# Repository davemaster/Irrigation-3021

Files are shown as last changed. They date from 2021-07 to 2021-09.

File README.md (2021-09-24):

# Irrigation-3021
imagen(https://blogs.embarcadero.com/building-good-with-cbuilder-contest-results/)

https://blogs.embarcadero.com/building-good-with-cbuilder-contest-results/ 
https://youtube.com/embed/tNYx-wSfjVc

imagen

How Bluetooth Technology can improve the use of water resources worldwide. Programming using [C++ Builder 10.3 Community Edition](https://www.embarcadero.com/es/products/cbuilder/starter) was surprisly very faster than the turtle of Android Studio and its eternal indexing-nightmares; So, its time to move forward using this IDE, in this project, using the multi-device features. 

The goal, more control over the water use in irrigation issues, first in my mom's garden, then in the city parks, then Farmlands, then in any water distribution activity worldwide. Thanks to the [Building Good with C++Builder Contest](https://blogs.embarcadero.com/building-good-with-cbuilder-contest/) for giving this oportunity.

# Project Resume
The system is going to use a bluetooth capable device to control a valve to irrigate a plant. The control-device can be a laptop/pc or a smartphone (Android or iOS). These devices control through bluetooth wireless link an Arduino UNO board connected to a HC-05 bluetooth module; so this last can open/close the solenoid valve by a relay; according the following modes: 1. Based on sensors (humidity, water tank level, and rain intensitivity) the Arduino will decide when to open/close the valve to properly water the plant. The sensors values will be compared with setpoints to make decisions. Mode 2. Test mode, we can open/close valve no matter the sensors values. Mode 3, using irrigation schedules, ie, time defined periods when the valve will be open.

# Needed Parts
1. Mobile Phone: Iphone, Android or laptop/pc Bluetooth capable. C++ Builder 10.3 can program them all with ONE project at the same time; pretty GOOD!!!.

imagen

2. Arduino Board: UNO, NANO, MEGA, etc. https://www.arduino.cc/en/Main/Products

imagen

3. HC-05 Bluetooth Module https://www.siarperu.com/store/#view=00011&busq=hc-05

imagen

4. A 12V solenoid Valve https://www.sparkfun.com/products/10456

imagen
 
5. Some Protoboards cabling, female-male, male-male or female-female https://naylampmechatronics.com/accesorios-y-prototipado/26-cable-para-protoboard.html

imagen

6. Sensors for Humidity moisture, rain intensitivity, and water level:

imagen  imagen imagen

# Needed Software
1. Embarcadero C++ Builder 10.3 Community Edition https://www.embarcadero.com/products/cbuilder/starter or lastest https://embarcadero.com/products/cbuilder

imagen

2. Arduino IDE 1.8.15 https://www.arduino.cc/en/software

imagen

3. Any Serial Terminal (for PC Windows or Mac where the C++ Builder is installed)

imagen

4. Proteus 8.6 with Arduino libraries for simulate Arduino valve control and the sensors attached (humidity, water leve, and rain) lectures and response of the valve
   control system (circuit and firmware) to commands from Irrigation 3021 app programmed in C++ Builder. 
   
   imagen

   imagen

5. In my particular case, I used the scrcpy for see my project (Irrigation 3021) in its Android versión. https://github.com/Genymobile/scrcpy

imagen

imagen

SOURCE CODE UPDATED

In file BTReadThread.cpp, the following changes has been made:

.................................

  else if(cmd==2)
		{
			dataFromArduino=Socket->ReceiveData();

			if(dataFromArduino.Length>0)
			{
				StrReceived = TEncoding::ASCII->GetString(dataFromArduino);

				/*************************************/
				AllReceivedData+=StrReceived;

				msg=AllReceivedData;
				Synchronize(TabbedForm->WriteMemo);

				if(AllReceivedData.Length()>12)
				{
					sensors=AllReceivedData;
					Synchronize(TabbedForm->UpdateValueSensors);

					AllReceivedData="";
					Sleep(100);
				}

				#ifndef __ANDROID__
				else
					AllReceivedData="";
				#endif

				/*****************************************/

				/*msg=StrReceived;
				Synchronize(TabbedForm->WriteMemo);

				if(msg.Length()>3)
				{

					sensors=StrReceived;
					Synchronize(TabbedForm->UpdateValueSensors);

				} */
			}

			Sleep(100);
		}

..................................

imagen

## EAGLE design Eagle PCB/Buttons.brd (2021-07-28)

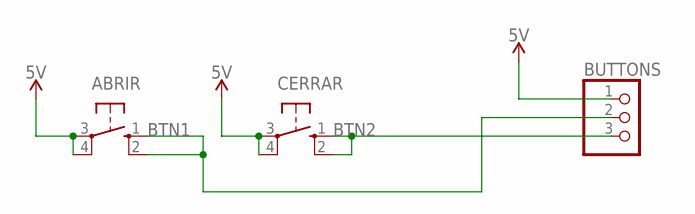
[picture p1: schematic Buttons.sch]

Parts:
ABRIR: 10-XX; B3F-10XX
BUTTONS: PINHD-1X3; 1X03
CERRAR: 10-XX; B3F-10XX

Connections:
5V: ABRIR.3, ABRIR.4 (P1), BUTTONS.1, CERRAR.3, CERRAR.4 (P1)
BTN1: ABRIR.1 (S), ABRIR.2 (S1), BUTTONS.2
BTN2: BUTTONS.3, CERRAR.1 (S), CERRAR.2 (S1)

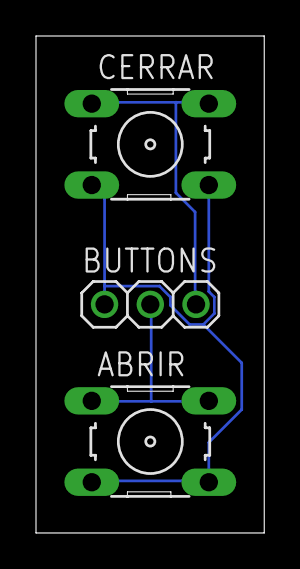
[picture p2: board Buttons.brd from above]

Board: 2 copper layers, 12.7 x 27.6 mm, 3 parts (0 on the bottom side), 3 nets.

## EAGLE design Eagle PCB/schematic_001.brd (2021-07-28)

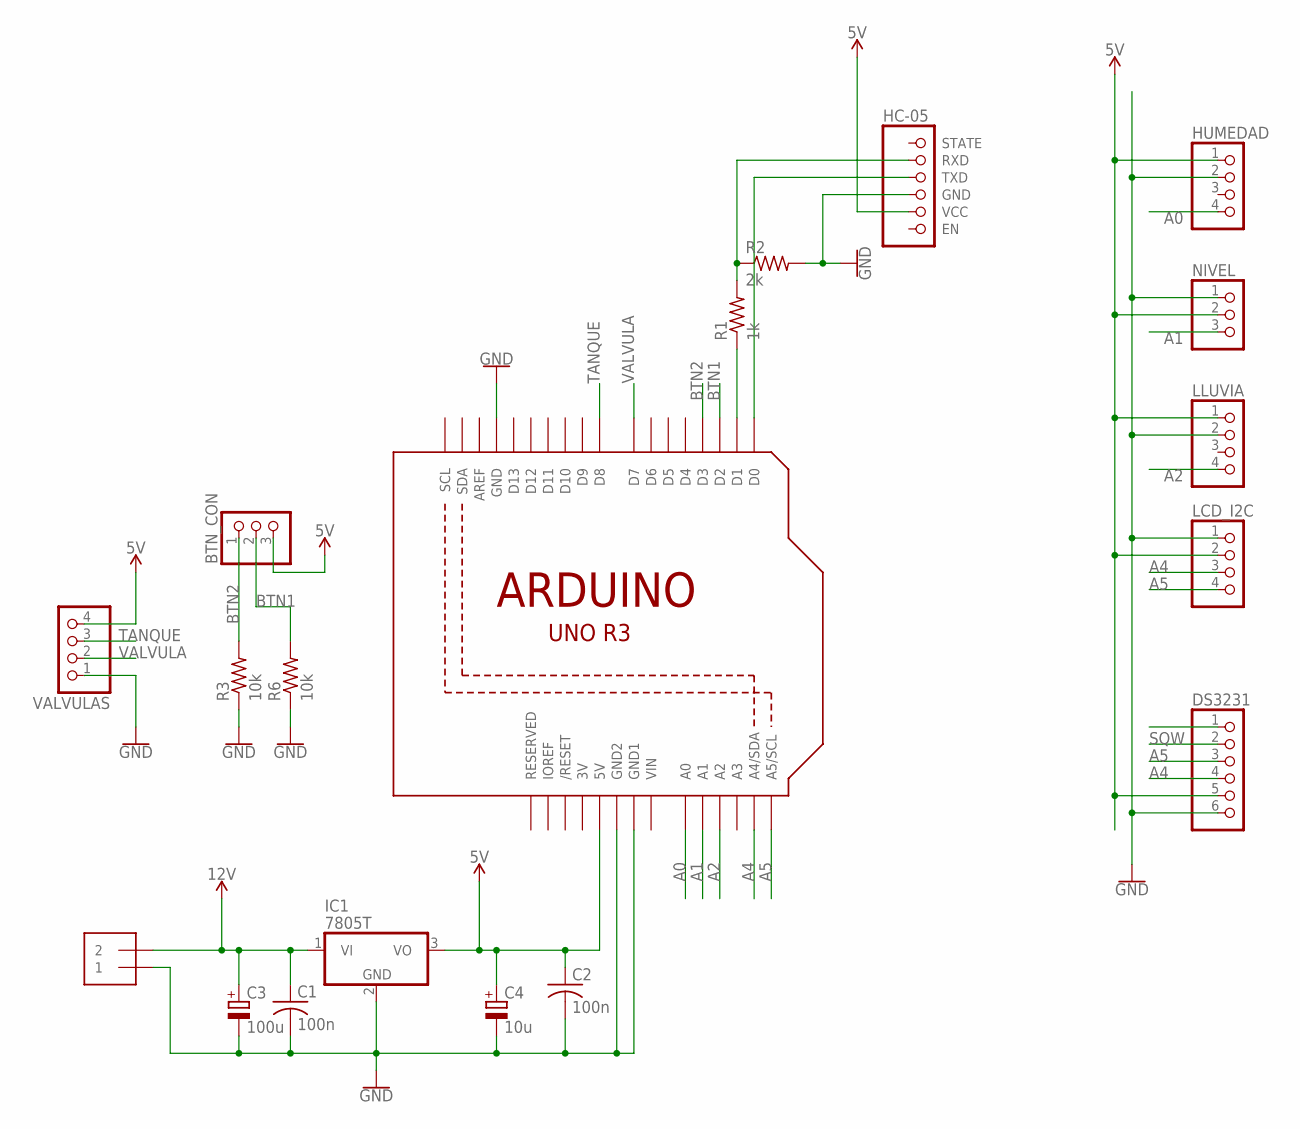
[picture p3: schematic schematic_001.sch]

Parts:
BTN_CON: PINHD-1X3; 1X03
C1, C2: 100n; C050-024X044
C3: 100u; E2,5-7
C4: 10u; E2,5-7
DS3231: PINHD-1X6; 1X06
HC-05: HC-05; 1X06
HUMEDAD: PINHD-1X4; 1X04
IC1: 7805T; TO220H
J1: 1X2-3.5MM
LCD_I2C: PINHD-1X4; 1X04
LLUVIA: PINHD-1X4; 1X04
NIVEL: PINHD-1X3; 1X03
R1: 1k; 0204/7
R2: 2k; 0204/7
R3, R6: 10k; 0204/7
U1: ARDUINOR3-BPLACE
VALVULAS: PINHD-1X4; 1X04

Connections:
3V: U1.3V
5V: BTN_CON.3, C2.1, C4.+, DS3231.5, HC-05.5 (VCC), HUMEDAD.1, IC1.3 (VO), LCD_I2C.2, LLUVIA.1, NIVEL.2, U1.5V, VALVULAS.4
12V: C1.1, C3.+, IC1.1 (VI), J1.2
A0: HUMEDAD.4, U1.A0
A1: NIVEL.3, U1.A1
A2: LLUVIA.4, U1.A2
A4: DS3231.4, LCD_I2C.3, U1.A4 (A4/SDA)
A5: DS3231.3, LCD_I2C.4, U1.A5 (A5/SCL)
BTN1: BTN_CON.2, R6.2, U1.D2
BTN2: BTN_CON.1, R3.2, U1.D3
GND: C1.2, C2.2, C3.-, C4.-, DS3231.6, HC-05.4 (GND), HUMEDAD.2, IC1.2 (GND), J1.1, LCD_I2C.1, LLUVIA.2, NIVEL.1, R2.2, R3.1, R6.1, U1.GND, U1.GND1, U1.GND2, VALVULAS.1
unnamed: HC-05.2 (RXD), R1.2, R2.1
unnamed: R1.1, U1.D1
unnamed: HC-05.3 (TXD), U1.D0
SQW: DS3231.2
TANQUE: U1.D8, VALVULAS.3
VALVULA: U1.D7, VALVULAS.2
VIN: U1.VIN

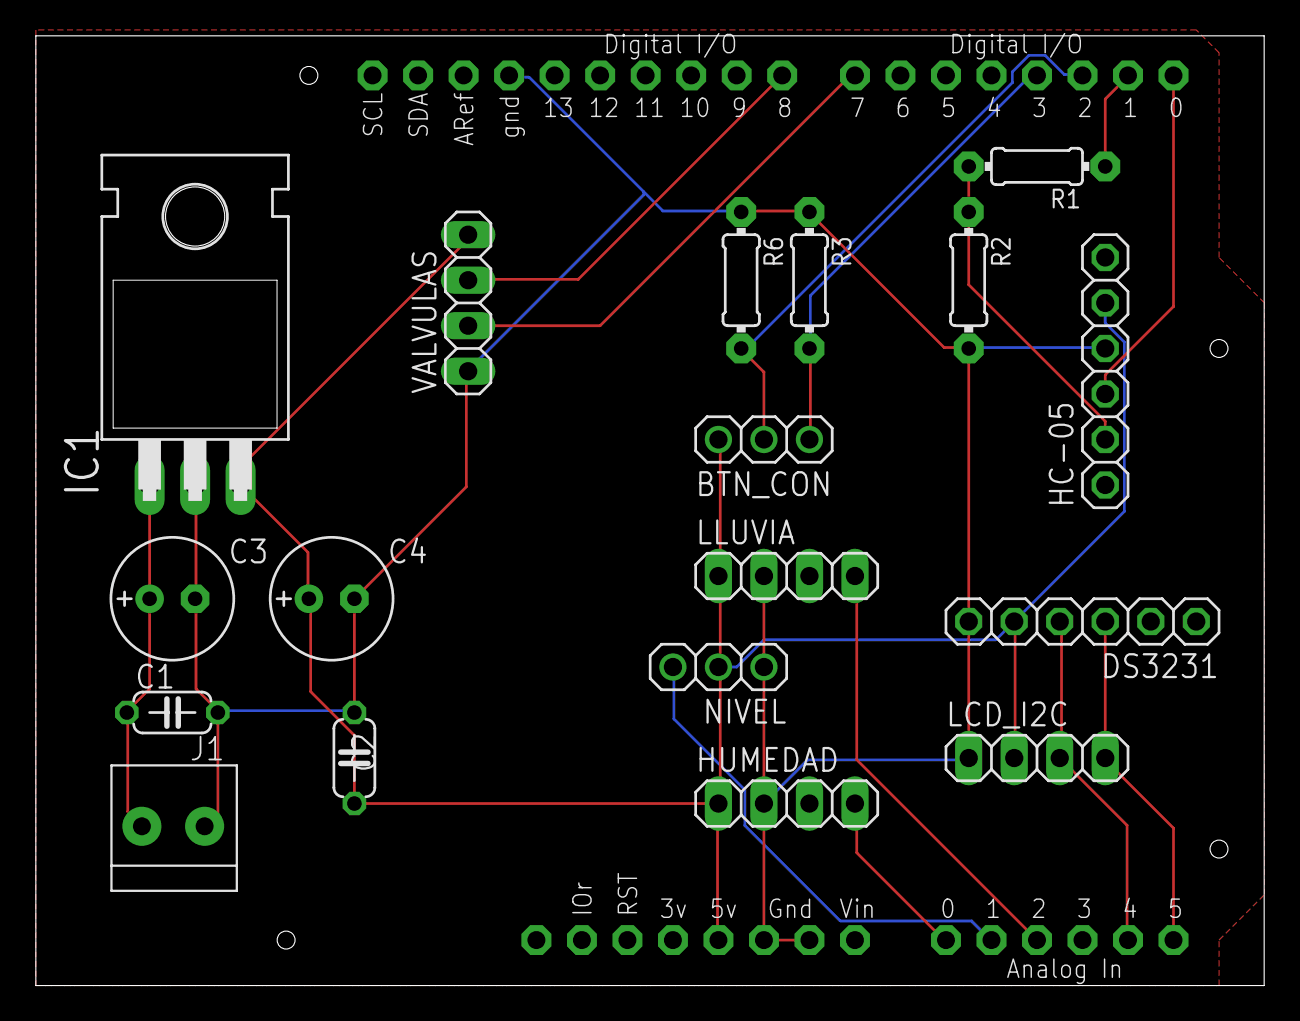
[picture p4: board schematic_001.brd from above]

Board: 2 copper layers, 68.6 x 53.0 mm, 19 parts (0 on the bottom side), 15 nets.

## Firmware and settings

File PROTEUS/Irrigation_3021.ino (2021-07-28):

/****************************************************************************************************************************
 * Project     :    Irrigation 3021
 * Programmer  :    David Elías Flores Escalante
 * github      :
 * Description :    Arduino sketch for Irrigation 3021 system for save water in irrigation applications in home, agriculture, 
 *                  etc. This for Contest C++ Builder Code for Good 2021
 **************************************************************************************************************************** 
 */


#include <Wire.h>
#include <LiquidCrystal_I2C.h>
#include <DS3231.h>


//********************************* Define an LCD object using I2C interface  ***********************************************

//LiquidCrystal_I2C lcd(0x27, 16, 2); // set the LCD address to 0x27 for a 16 chars and 2 line display
LiquidCrystal_I2C lcd(0x20,16,2);  // set the LCD address to 0x27 for a 16 chars and 2 line display

//**********************************************Variables RTC DS3231 ********************************************************
DS3231 clock;

byte Year;
byte Month;
byte Date;
//byte DoW;
byte Hour;
byte Minute;
byte Second;
int lastSecond = 20; //Initial absurd second value

bool h12Flag;
bool pmFlag;

//***************************************************************************************************************************

//******************************************Variables RTC DS3231 ************************************************************
int sensorHumedad = A0;                 //   Humidity Sensor
int sensorNivelAgua = A1;               //   Water Level Sensor
int sensorLluvia = A2;                  //   Rain Intensitivity Sensor
int valvePin = 7;                       //   Valve for water
int valveTanquePin = 8;                 //   valve of tank of water from rain
//int ledPin = 13;

// countdown timer vars
int openMinutes = 5;                    //   time in minutes during valve will be open
int openSeconds = 0;
RTClib myRTC;
DateTime dTime;
long startTime, currentTime;
//long endTime;



// setpoints
const int defaultHumedad = 400;         //   default humidity sensor setPoint
const int defaultNivel   = 500;         //   default water level sensor setPoint
const int defaultLluvia  = 500;         //   default rain intenwitivity sensor setPoint

int setPointHumedad      = 400;         //   current humidity sensor setPoint
int setPointNivelAgua    = 500;         //   current water level sensor setPoint
int setPointLluvia       = 500;         //   current rain intenwitivity sensor setPoint

const int BTN_OPEN       = 3;           //   button arduino pin for open valve
const int BTN_CLOSE      = 2;           //   button arduino pin for close valve

int buttonState          = 0;           //   variable for reading the pushbutton status
int valveStatus          = 0;           //   variable valve status 1: open     0: closed
int valveTanqueStatus    = 0;           //   variable valve status 1: open     0: closed

long sensorValueHumedad;                //   value of Analog port for humidity
long sensorValueNivelAgua;              //   value of Analog Port for Water Level
long sensorValueLluvia;                 //   value of Analog port for Rain Intensitivity

//int limit = 300;

#define SAMPLES 10                      //   number of samples for Analog ports lectures

/***************************************
  SERIAL BLUETOOTH LINK
**************************************/

//int cmd = 0;
int Modo = 3;
byte prevVal1, prevVal2, val, dataBuffer[256];
boolean dataIn = false;
int dataPos = 0;

/*******************************************************************************************

   Function setup, executed ONCE for set Arduino features

********************************************************************************************/
void setup()
{
  /***********************************************************************
     buttons open & close valve into interrupted fired ports (2 & 3 for Arduino UNO)
  ***********************************************************************/
  // digital pin 2 - open valve button
  attachInterrupt(digitalPinToInterrupt(BTN_OPEN), btnValveOpen, CHANGE);

  // digital pin 3 - close valve button
  attachInterrupt(digitalPinToInterrupt(BTN_CLOSE), btnValveClose, CHANGE);

  loadConfiguration();
}

/*******************************************************************************************

   Function for Arduino settings

********************************************************************************************/
void loadConfiguration()
{
  //pinMode(ledPin, OUTPUT);
  pinMode(valvePin, OUTPUT);              // set valvePin to OUTPUT
  pinMode(valveTanquePin, OUTPUT);        // set valveTanquePin to OUTPUT

  lcd.init();                             // initialize the LCD-I2C

  lcd.backlight();                        // turn LCD-I2C backlight on
  lcd.setCursor(0, 0);
  lcd.print("DaveWare Design.");
  lcd.setCursor(0, 1);
  lcd.print("Irrigation 3021 ");
  delay(3000);
  lcd.clear();

  //lcd.noBacklight();                    // turn LCD-I2C backlight off

  Serial.begin(9600);                     // set Serial port (Bluetooth attached here) to 9600 bps spped

  // Finally the hour, minute, and second
  Serial.println(" ");
  Serial.print(clock.getHour(h12Flag, pmFlag), DEC);
  Serial.print(" ");
  Serial.print(clock.getMinute(), DEC);
  Serial.print(" ");
  Serial.print(clock.getSecond(), DEC);
  
}

/*******************************************************************************************

   Function that read dataBuffer and get humidity setpoint sent by pc/android application

********************************************************************************************/
void getHumidityFromBT(int& humditySP)
{
  byte Temp1, Temp2;                      // temp variables for convert bytes with time values
  byte Temp3, Temp4;                      // temp variables for convert bytes with time values

  // Reading from Most to less significant digits
  Temp1 = dataBuffer[0] - 48;
  Temp2 = dataBuffer[1] - 48;
  Temp3 = dataBuffer[2] - 48;
  Temp4 = dataBuffer[3] - 48;
  humditySP = Temp1 * 1000 + Temp2 * 100 + Temp3 * 10 + Temp4;

}

/*******************************************************************************************

   Function that read dataBuffer and get Water Level setpoint sent by pc/android application

********************************************************************************************/
void getLevelFromBT(int& LevelSP)
{
  byte Temp1, Temp2;                      // temp variables for convert bytes with time values
  byte Temp3, Temp4;                      // temp variables for convert bytes with time values

  // Reading from Most to less significant digits
  Temp1 = dataBuffer[0] - 48;
  Temp2 = dataBuffer[1] - 48;
  Temp3 = dataBuffer[2] - 48;
  Temp4 = dataBuffer[3] - 48;
  LevelSP = Temp1 * 1000 + Temp2 * 100 + Temp3 * 10 + Temp4;
}


/*******************************************************************************************

   Function that read dataBuffer and get Rain Intenisivity setpoint sent by pc/android application

********************************************************************************************/
void getRainFromBT(int& RainSP)
{
  byte Temp1, Temp2;                      // temp variables for convert bytes with time values
  byte Temp3, Temp4;                      // temp variables for convert bytes with time values

  // Reading from Most to less significant digits
  Temp1 = dataBuffer[0] - 48;
  Temp2 = dataBuffer[1] - 48;
  Temp3 = dataBuffer[2] - 48;
  Temp4 = dataBuffer[3] - 48;
  RainSP = Temp1 * 1000 + Temp2 * 100 + Temp3 * 10 + Temp4;
}

/***********************************************************************************************

   Function that read dataBuffer and get Time of Valve Operation sent by pc/android application

***********************************************************************************************/
void getMinutesFromBT(int& vMinutes)
{
  byte Temp1, Temp2;                      // temp variables for convert bytes with time values
  byte Temp3, Temp4;                      // temp variables for convert bytes with time values

  // Reading from Most to less significant digits
  Temp1 = dataBuffer[0] - 48;
  Temp2 = dataBuffer[1] - 48;
  Temp3 = dataBuffer[2] - 48;
  Temp4 = dataBuffer[3] - 48;
  vMinutes = Temp1 * 1000 + Temp2 * 100 + Temp3 * 10 + Temp4;
}

/*******************************************************************************************

   Function that read dataBuffer when a "Sincronize time" is sent by pc/android application

********************************************************************************************/
void getDateFromBT(byte& Year, byte& Month, byte& Day,
                   byte& Hour, byte& Minute, byte& Second)
{
  // Call this if you notice something coming in on
  // the serial port. The stuff coming in should be in
  // the order YYMMDDHHMMSS, with an 'x' at the end.

  byte Temp1, Temp2;                      // temp variables for convert bytes with time values

  // Read Year first
  Temp1 = dataBuffer[0] - 48;
  Temp2 = dataBuffer[1] - 48;
  Year = Temp1 * 10 + Temp2;
  // now month
  Temp1 = dataBuffer[2] - 48;
  Temp2 = dataBuffer[3] - 48;
  Month = Temp1 * 10 + Temp2;
  // now date
  Temp1 = dataBuffer[4] - 48;
  Temp2 = dataBuffer[5] - 48;
  Day = Temp1 * 10 + Temp2;
  // now Day of Week
  //DoW = (byte)dataBuffer[6] - 48;
  // now Hour
  Temp1 = dataBuffer[6] - 48;
  Temp2 = dataBuffer[7] - 48;
  Hour = Temp1 * 10 + Temp2;
  // now Minute
  Temp1 = dataBuffer[8] - 48;
  Temp2 = dataBuffer[9] - 48;
  Minute = Temp1 * 10 + Temp2;
  // now Second
  Temp1 = dataBuffer[10] - 48;
  Temp2 = dataBuffer[11] - 48;
  Second = Temp1 * 10 + Temp2;
}

/*******************************************************************************************

   Function loop, this is executed continously

********************************************************************************************/
void loop()
{
  /***************************************************
     Humidity Sensor Readings
  ***************************************************/
  //set value of humidity sensor to zero
  sensorValueHumedad = 0;
  //reading samples to average measurements
  for (int ind = 0; ind < SAMPLES; ind++)
  {
    int value = analogRead(sensorHumedad);
    sensorValueHumedad = sensorValueHumedad + value;
    delay(10);                                   // wait 10 milliseconds
  }

  //humidity sensor average value
  sensorValueHumedad = sensorValueHumedad / SAMPLES;

  /***************************************************
     Water Level Sensor Readings
  ***************************************************/
  //set value of Water Level sensor to zero
  sensorValueNivelAgua = 0;

  //reading samples to average measurements
  for (int ind = 0; ind < SAMPLES; ind++)
  {
    int value = analogRead(sensorNivelAgua);     // Read the analog value form sensor
    sensorValueNivelAgua = sensorValueNivelAgua + value;
    delay(10);                                   // wait 10 milliseconds
  }
  //Water Level sensor average value
  sensorValueNivelAgua /= SAMPLES;

  /***************************************************
     Rain Intensitivity Sensor Readings
  ***************************************************/
  //set value of Rain Intensitivity sensor to zero
  sensorValueLluvia = 0;

  //reading samples to average measurements
  for (int ind = 0; ind < SAMPLES; ind++)
  {
    int value = analogRead(sensorLluvia);        // Read the analog value form sensor
    sensorValueLluvia = sensorValueLluvia + value;
    delay(10);                                   // wait 10 milliseconds
  }
  //Rain Intensitivity sensor average value
  sensorValueLluvia /= SAMPLES;

  if (Modo == 3) //Normal Mode / Modo Normal
  {
    char buffer[20];
    int curSecond = clock.getSecond();

    if (lastSecond != curSecond)
    {
      sprintf(buffer, "Hora--> %02d:%02d:%02d", clock.getHour(h12Flag, pmFlag)
              , clock.getMinute()
              , lastSecond); //,clock.getSecond());
      lastSecond = curSecond;

      //Serial.println(buffer);
      lcd.setCursor(0, 1);
      lcd.print(buffer);
    }

    if (sensorValueLluvia > setPointLluvia)
    {
      if (sensorValueNivelAgua < setPointNivelAgua - 100)
      {
        digitalWrite(valveTanquePin, LOW);
        valveTanqueStatus = 0;
        if (sensorValueHumedad < setPointHumedad - 100)
        {
          digitalWrite(valvePin, LOW);
          valveStatus = 0;
          lcd.setCursor(0, 0);
          lcd.print("Valvula   ");
          lcd.setCursor(8, 0);
          lcd.print("Cerrada   ");
        }
        else if (sensorValueHumedad > setPointHumedad)
        {
          digitalWrite(valvePin, HIGH);
          valveStatus = 1;
          lcd.setCursor(0, 0);
          lcd.print("Valvula   ");
          lcd.setCursor(8, 0);
          lcd.print("Abierta   ");
        }
      }
      else if (sensorValueNivelAgua > setPointNivelAgua)
      {
        digitalWrite(valvePin, LOW);
        valveStatus = 0;

        if (sensorValueHumedad < setPointHumedad - 100)
        {
          digitalWrite(valveTanquePin, LOW);
          valveTanqueStatus = 0;
          lcd.setCursor(0, 0);
          lcd.print("Tanque   ");
          lcd.setCursor(8, 0);
          lcd.print("Cerrado   ");
        }
        else if (sensorValueHumedad > setPointHumedad)
        {
          digitalWrite(valveTanquePin, HIGH);
          valveTanqueStatus = 1;
          lcd.setCursor(0, 0);
          lcd.print("Tanque   ");
          lcd.setCursor(8, 0);
          lcd.print("Abierto   ");
        }
      }
    }
    else //if(sensorValueLluvia<setPointLluvia)
    {
      lcd.setCursor(8, 0);
      lcd.print("Lluvia  ");

      digitalWrite(valvePin, LOW);
      valveStatus = 0;
      digitalWrite(valveTanquePin, LOW);
      valveTanqueStatus = 0;
    }
  }

  else if (Modo == 2) //modo test
  {
    char buffer[20];

    Serial.print("humedad Value : ");
    Serial.println(sensorValueHumedad);
    Serial.print("Nivel Value : ");
    Serial.println(sensorValueNivelAgua);
    Serial.print("Lluvia Value : ");
    Serial.println(sensorValueLluvia);

    int valor = sensorValueHumedad;
    sprintf(buffer, "H: %4u", valor);
    lcd.setCursor(0, 0);
    lcd.print(buffer);

    lcd.setCursor(0, 1);
    valor = sensorValueNivelAgua;
    sprintf(buffer, "N: %4u", valor);
    lcd.print(buffer);

    lcd.setCursor(8, 1);
    valor = sensorValueLluvia;
    sprintf(buffer, "LL: %4u", valor);
    lcd.print(buffer);

    lcd.setCursor(8, 0);
    lcd.print("Prueba    ");

  }

  else if (Modo == 1) //modo setup: cambia setpoints, humedad,nivel, lluvia
  {
    Serial.print("humedad Value : ");
    Serial.println(sensorValueHumedad);
    Serial.print("Nivel Value : ");
    Serial.println(sensorValueNivelAgua);
    Serial.print("Lluvia Value : ");
    Serial.println(sensorValueLluvia);

    // lcd.backlight();
    lcd.setCursor(0, 0);
    lcd.print("H: ");   lcd.print(sensorValueHumedad);
    lcd.setCursor(8, 0);
    lcd.print("Setup    ");
    lcd.setCursor(0, 1);
    lcd.print("N: "); lcd.print(sensorValueNivelAgua);
    lcd.setCursor(8, 1);
    lcd.print("LL: "); lcd.print(sensorValueLluvia);
    //delay(3000);
    // lcd.noBacklight();
  }

  else if (Modo == 5) //Sincronize time in Ds3231 from Phone/PC by Bluetooth
  {
    char buffer[20];

    getDateFromBT(Year, Month, Date,  Hour, Minute, Second);

    clock.setClockMode(false);    // set to 24h
    //setClockMode(true);         // set to 12h

    clock.setYear(Year);
    clock.setMonth(Month);
    clock.setDate(Date);
    //clock.setDoW(DoW);
    clock.setHour(Hour);
    clock.setMinute(Minute);
    clock.setSecond(Second);

    sprintf(buffer, "Valve Sincronized");

    lcd.setCursor(0, 0);
    lcd.print(buffer);

    if (Serial)
      Serial.println("Date & Time sinchronized");

    delay(3000);
    Modo = 3;                     // return to NORMAL mode
  }

  else if (Modo == 6) //change Humidity SetPoint
  {
    char buffer[20];

    getHumidityFromBT(setPointHumedad);

    sprintf(buffer, "Humidity ->  %d", setPointHumedad);

    //Serial.println(buffer);
    lcd.setCursor(0, 0);
    lcd.print(buffer);

    delay(3000);
    Modo = 3;

  }

  else if (Modo == 7) //change Water Level SetPoint
  {
    char buffer[20];

    getLevelFromBT(setPointNivelAgua);

    sprintf(buffer, "Water SP ->  %d", setPointNivelAgua);

    //Serial.println(buffer);
    lcd.setCursor(0, 0);
    lcd.print(buffer);

    delay(3000);
    Modo = 3;
  }

  else if (Modo == 8) //change Rain Intenistivity SetPoint
  {
    char buffer[20];

    getRainFromBT(setPointLluvia);

    sprintf(buffer, "Rain  SP ->  %d", setPointLluvia);

    lcd.setCursor(0, 0);
    lcd.print(buffer);

    delay(3000);
    Modo = 3;
  }

  else if (Modo == 9) //open valve during a time set by app/pc
  {
    //RTClib myRTC;
    char buffer[20];
    /*DateTime*/ dTime = myRTC.now();

    getMinutesFromBT(openMinutes);

    openSeconds = openMinutes * 60;

    startTime = dTime.unixtime();

    digitalWrite(valvePin, HIGH);                //   Open valve of water

    sprintf(buffer, "Valve Open %d Min", openMinutes);

    lcd.setCursor(0, 0);
    lcd.print(buffer);

    delay(3000);
    Modo = 99;
  }

  else if (Modo == 10) //Valve Open
  {
    char buffer[20];

    digitalWrite(valvePin, HIGH);                //   Open valve of water

    sprintf(buffer, "Test - Valve Open");

    lcd.setCursor(0, 0);
    lcd.print(buffer);

    delay(3000);
    //Modo=3;
  }

  else if (Modo == 11) //Close Valve
  {
    char buffer[20];

    digitalWrite(valvePin, LOW);                //   Open valve of water

    sprintf(buffer, "Test - Close Valve");

    lcd.setCursor(0, 0);
    lcd.print(buffer);

    delay(3000);
    Modo = 3;
  }

  else if (Modo == 99) //check new second value from DS3231
  {
    //RTClib myRTC;
    char buffer[20];
    /*DateTime*/ dTime = myRTC.now();

    currentTime = dTime.unixtime();

    //long elapsedTime = currentTime - startTime;

    if(currentTime>startTime)
	{
          openSeconds--;
		  startTime=currentTime;
	}

    if (openSeconds <=0)
    {
      digitalWrite(valvePin, LOW);                //   Close water valve after time is elapsed

      sprintf(buffer,"Test-Close Valve");

      currentTime=0;

      lcd.setCursor(0, 0);
      lcd.print(buffer);
	   

      delay(3000);
      Modo = 3;
    }
    else
	{
		sprintf(buffer,"Valve Open- %u",openSeconds);		

		lcd.setCursor(0, 0);
		lcd.print(buffer);
		
		sprintf(buffer, "Hora--> %02d:%02d:%02d", clock.getHour(h12Flag, pmFlag)
												, clock.getMinute()
												, lastSecond); //,clock.getSecond());		

		//Serial.println(buffer);
		lcd.setCursor(0, 1);
		lcd.print(buffer);
	
      Modo = 99;
	}
  }
}

/*******************************************************************************************

   Function btnValveOpen, executed with BUTON_OPEN interrupt in port 2

********************************************************************************************/
void btnValveOpen()
{
  if (Modo == 3) //en modo Normal, no opera
    return;
  buttonState = digitalRead(BTN_OPEN);
  if (buttonState == LOW)
  {
    buttonState = digitalRead(BTN_OPEN);
    if (buttonState == LOW)
    {
      digitalWrite(valvePin, HIGH);
      valveStatus = 1;
      delay(25);
    }
  }
}

/*******************************************************************************************

   Function btnValveOpen, executed with BUTON_CLOSE interrupt in port 3

********************************************************************************************/
void btnValveClose()
{
  if (Modo == 3) //en modo Normal, no opera
    return;
  buttonState = digitalRead(BTN_CLOSE);
  if (buttonState == LOW)
  {
    buttonState = digitalRead(BTN_CLOSE);
    if (buttonState == LOW)
    {
      digitalWrite(valvePin, LOW);
      valveStatus = 0;
      delay(25);

    }
  }
}

/*******************************************************************************************

   Function that manages serial port interrupt (received data) from Bluetooth HC-05 module
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

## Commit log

2021-07-27 Rename irrigation_3021.inoE to Arduino/irrigation_3021.ino
    sketch tested on Arduino UNO
2021-07-28 Add files via upload
    Eagle PCB Board. Builded by NEXTPCB.
    [Buttons.brd, Buttons.sch, schematic_001.brd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]
2021-07-30 Changes in BTReadThread.cpp file
    The following changes was made for reading the setpoints of sensors from Valve in both, windows, and Android:
    .................
    else if(cmd==2)
    {
    dataFromArduino=Socket->ReceiveData();
    if(dataFromArduino.Length>0)
    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

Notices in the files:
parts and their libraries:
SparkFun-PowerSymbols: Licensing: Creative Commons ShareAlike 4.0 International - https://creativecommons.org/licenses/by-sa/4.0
